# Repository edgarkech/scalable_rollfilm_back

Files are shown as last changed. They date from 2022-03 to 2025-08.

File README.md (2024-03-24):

# Scalable rollfilm back - 6x9...6x17...maybe even 6x24? 

_This is my attempt to re-engineer my old 6x12 rollfilm back into a scalable and adaptable design for large format cameras (4x5", 5x7", maybe 8x10")._
_

As a starting point - here's my old 6x12 TinkerCAD-design: https://www.thingiverse.com/thing:2894651 

## Project goals:
- of course a 3d printable and usable rollfilm back.
- different formats possible with type 120 rollfilm - from 6x6 up to 6x24 (depending on the targeted camera format) 
- The design should be scalable for being used with 4x5", 5x7" or even 8x10" large format cameras by just changing a handful of variables. I am not targeting medium format cameras/platforms like Mamiya RB/RZ, Bronica EC/GS/SQ/ETR, Hasselblad, Kiev88, Horseman 6x9, Graflex 2x3, Fuji GX or any other format smaller than 4x5". It _may_ be possible to scale down and fit the design to some 6x9/2x3" platforms, but I won't make any changes just for scaling down.  
- Improving my OpenSCAD skills. Learning to use it efficiently. Learning to do good parametric development/design.
- Learning git/github and sharing my code with other people
- Checking out the limits of home 3D printing with a very limited set of available tools

## Some technical goals:
- modular+parametric design
- all parts must be either 3D-printable or easily available via Amazon, eBay, Aliexpress or Temu.
- no special tools required besides a decent 3D printer and some common tools like little files, screwdrivers, sanding paper, cutter, scissors, ...
- no exotic third party parts/components
- form follows function
- KISS

## Early design decisions:
- keeping the basic concepts of my old 6x12 back
  - no explicit pressure plate
  - film "rollers" are fixed because it's easier to keep the measures/tolerances
- parts for the base plate won't be glued (except dark slide light seal) ==> dovetails
- film "roller"/re-director will be integrated and printed
- less "cubical" design than first version; maybe even flat enough to slide the back under the ground glass
- using the excellent BOSL2 library https://github.com/revarbat/BOSL2/wiki 
- no "extension" over the targeted platform and thus avoiding to move the film plane back (and using spacers or dedicated ground glassses): max format for 4x5" will be 6x12, max format for 5x7" will be 6x17

## update 2024-03-01
- looks like it will be a bit more re-engineering than just "porting" my old design to OpenSCAD. After having a look at some other (commercial) roll film backs like the Super Rollex or the Toyo family, I will also use some inspirations from there.

## update 2024-03-17 
- I always wanted to ge rid of the screws for locking cover and baseplate together, so I am now locking cover, baseplate_top and baseplate_bottom via dovetails.
- currently missing / not yet (re-) designed:
  - advancing lever ==> I am currently evaluating different ratchet mechanisms/designs
  - spool holders ==> will be quite simple parts
  - film counter ==> for the first version I will stick to the "spy window"
  - light seal for the baseplate bottom, but this is just a simple cubical to be glued into the base plate
  - STLs. I didn't print any parts yet and it will probably take one or two itereations for all the tolerances to match.

## update 2024-03-19
- printable parts are almost complete
  - avancing lever is derived from a little ratchet tool
  - film insert and cover got a counter window
  - film insert is prepared for a unrolling preventer (to be made of spring steel wire)
  - I am progressing with winders and spool holders
- now it's time for lots of test printing.
  - first test prints of the back plate revealed some small glitches (already fixed).
  - first complete prototype will hopefully available by the upcoming weekend...

 ## update 2024-03-24
 - meanwhile I printed all major parts.
 - the parts are fitting together, but showed the need for minor fixes/improvements (mostly printing related)
 - next iteration is leaving "mockup" stage and should be able to perform the basic mechanical functions (film loading, film advancing, disassembling without tools) 
   - clearance for the film spool inside the film insert was too tight (already fixed)
   - replaced some cube() objects with cuboid() from the BOSL2 library to round some edges (already done)
   - test with printed dark slide instead of sheet metal (cutting a raft from one of the prints), added file for printed dark slide
   - printing related optimizations
   - some minor parts are still missing: back plate light seal, winder blade, knob for film spool missing, lid for film counter window   

**Some very kind people asked me about the possibility to show their appreciation by donating to me.**

If you really felt somehow obliged to do so, then you should use https://paypal.me/EdgarKech :-) .
But I am also happy if you post pictures of your build to https://www.facebook.com/groups/3dprinting.and.analog.photography/

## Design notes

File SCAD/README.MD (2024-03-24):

CAUTION: 
The current version is not tested!!!

Preparation:

1.) Please make sure to install a fairly new version of OpenSCAD - versions 2021.01 or above are recommended and should be available for all common OS platforms.

2.) Please make sure to pull and install the following modules/libraries:

https://github.com/revarbat/BOSL2
==> we are using some modules/functions from this quite comprehensive library, e.g. dovetails, rectangular tubes, cuboids, trapezoids, ...

3.) Review and modify the configuration in config.scad to your needs. For the most common target "platforms" and formats you will just have to choose and uncomment some variables. Just read&follow the comments in the config.scad file. 

Modification beneath simple configuration:

Naming and scripting conventions (tbd)

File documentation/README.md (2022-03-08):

# Documentation

Here's an attempt at guiding the assembly and build process of the Scalable Rollfilm Back.

For now, it only contains NOTHING but we aim to create a step-by-step guide soon :)

**The assembly images are based on the 4x5" camera files**

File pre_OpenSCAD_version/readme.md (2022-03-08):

Here you can find the "old" files from my initial TinkerCAD-version.
You will find a set of STL files as well as f3d files.
For hints about the old version, have a look at https://www.thingiverse.com/thing:2894651

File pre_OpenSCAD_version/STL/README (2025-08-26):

### Summary
Roll film back for shooting 6x12cm format with 4x5 cameras.
The basic idea is borrowed from the chinese DaYi / ShenHao roll film backs.
Main design principle is to keep it as simple as possible and avoiding special or exotic third party parts or tools.

# Third party parts:
2x rods or tubes with a diameter of 6mm and a length of 72mm
2x countersunk screws M6x30mm
2x butterfly or knurled nuts M6
1x dark red gel with about 14mm for the frame counter window (optional)
1x sheet metal 170x70x0.5mm for dark slide (170mm is about the minimum length)
2x sheet metal from a tin can, about 20x60mm
a little bit of plastic glue
1x velvet ribbon, about 10x90mm as light seal for the dark slide

Pictures shot with my design can be found here:
https://www.flickr.com/search/?text=6x12%20istillshootfilm%20buyfilmnotmegapixels%20back&sort=date-posted-desc

### Changes
- 2020-01-25 updated the base plate top (slightly higher light seal, corrected flange measurements)
- 2020-01-26 updated the cover because it was a little bit to tight on the film insert. New version has about 0.2mm more space on each side. This helps also, if you are using some colored filament and thus have to paint the inside of the cover in black. 
- 2020-02-02 updated base plate bottom and base plate top to new version 2.4.
I added a wall at one side and on the other side an indent for a light seal (glue velvet ribbon into the indent.
Also updated the pictures to ones from the latest build and removed the ones from the old version.
- 2020-02-07 tried to get the previews of all STL-files back. No changes, just renaming the files to reflect the overall version
- 2020-02-08 added link to my flickr page
- 2020-03-06 updated base plate top to v2.5 because of a little error.
- 2020-03-19 updated text and instructions regarding dark slide (now minimum length of about 170mm)
- 2021-08-11 I finally managed to export my design files from TinkerCAD to Fusion360 and then download/upload as .f3d files , so interested/gifted designers may now be able to modify my design in a more convenient way than using .stl files...

### Print Settings
Printer brand:
- any brand will do, as long as you have a basic understanding of printing and especially bed leveling

Printer:
- any model will do, as long as you have a basic understanding of printing and especially bed leveling

Rafts:
- if you have problems with printing bed adhesion, rafts could be an option, but I'd rather recommend doing proper bed leveling

Resolution:
- 0.1-0.15

Infill:
- depending on part, see below

Filament brand:
- choose your favorite

Filament color:
- preferably black

Filament material:
- PLA, ABS, PETG

### Notes:
We have to get the roll film back really light tight, so make sure to use some kind of really opaque filament.
Make sure to print at least 4 walls and 8 bottom/top layers - we have to get some parts really light tight (base plate, film insert, cover, counter window blade)!

- base plate bottom: 0.1mm layer, 100% infill, no support, 3mm brim
- base plate top: 01.mm layer, 100% infill, no support, 3mm brim
- film insert: 0.1mm layer, 66%infill, support, 3mm brim
- cover: 0.1mm layer, 66% infill, support, 3mm brim
- all smaller parts: 0.1mm layer, 100% infill, no support, 3mm brim

### Post-Printing
# base plate
After removing the brim and cleaning up the edges of the base plate parts, glue the velvet ribbon into the indent.
Then glue the "base plate top" to the "base plate bottom". Make sure that no glue gets into the dark slide slot, otherwise it'll get very difficult to pull in/out the dark slide.
Glue the bottom wall into the slot at the bottom side 

# film insert
Remove brim and support structures, then clean up the edges with sandpaper or a little file.
Press the two 6mm rods into their places at the bottom. They should be even with the bottom.
Clean up the edges of your tin can stripes with a little file. Put the stripes into the slots in the inner walls. Bend the stripes down so they will put a little bit tension onto the film roll and prevent the film of unrolling.
Counter window blade and film holder brackets:
You may use a file to trim those parts a little bit so they slide into their respective guides. Be careful not to trim away too much - you should be able to move them in their guides with just a little force.

# cover
Remove brim and support structures from the cover.
Check with a small, but very bright flashlight, if your cover (upper side, end faces) is really light tight. If not, paint the inside of the cover with black paint.
If it is still not light tight, print the cover with black filament and 100% infill.

# winders / winder knobs
Once again, remove brim and sharp edges. On the smaller side of the winder plate use a file or sandpaper to make it a bit "wedgy". Then press it into the slot of the winder (the part with the cube on top of the cylinder. Put the winders into the film insert and press the winder knob onto it -  the bigger one on the right hand side, the smaller on the left (maybe you have to add a drop of glue).  

# dark slide
Make sure you have a perfectly flat sheet metal 170x70x0.5mm. Bend the last few millimeters to a grip (fold 5mm then bend the 5mm double to a right angle).
Now the most important thing:
As we don't have a light seal, we simply just don't pull out the dark slide completely. Instead we make marks onto the slide which show us, how far we can pull it out.
Just put the dark slide into the dark slide slot of the back and pull it out until the window frame is completely open. Now mark the position on the darkslide (for example with small notches on the sides of the dark slide).

### Testing & correcting film guidance
You will have to sacrifice one or two rolls of film to get everything working.
You may notice that the slot where the film is pulled through, is very tight.
If it is too tight, then just apply strips of tape onto the base plate's guides.

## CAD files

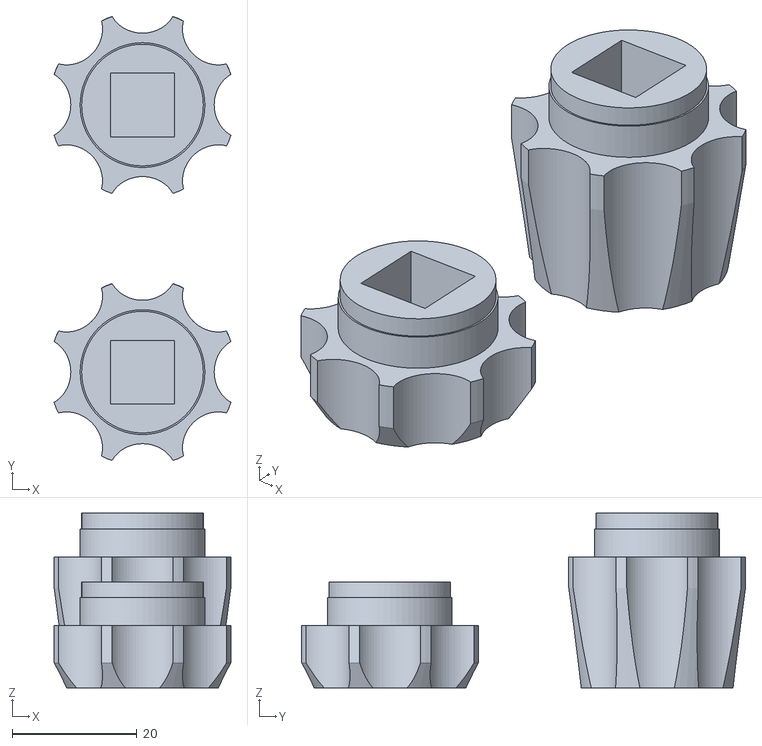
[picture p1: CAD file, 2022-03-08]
pre_OpenSCAD_version/STL/winder_knobs_v2.4.stl
28.4 x 71.2 x 28.0

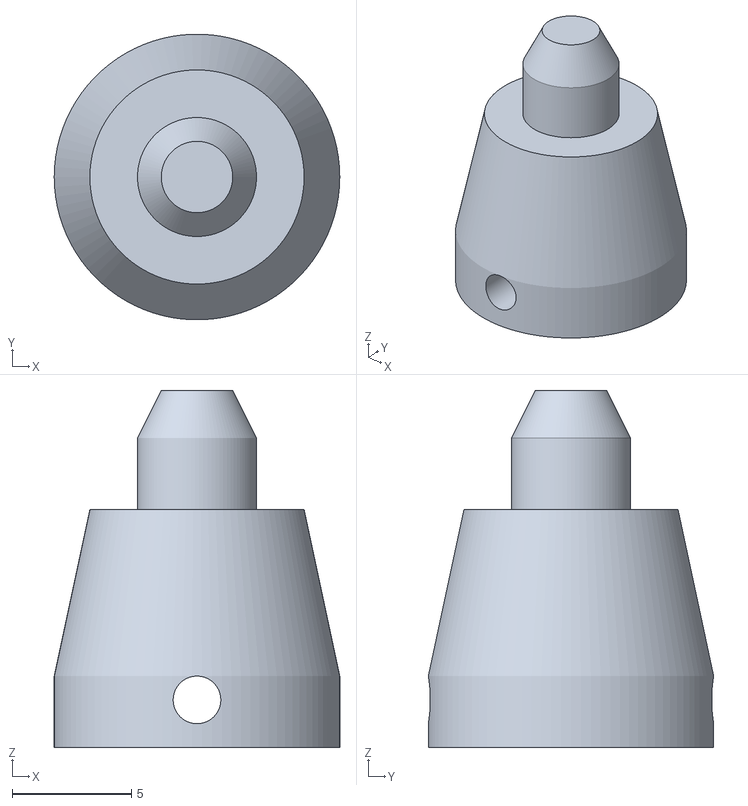
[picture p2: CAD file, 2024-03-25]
STL/spoolholder.stl
12.0 x 12.0 x 15.0

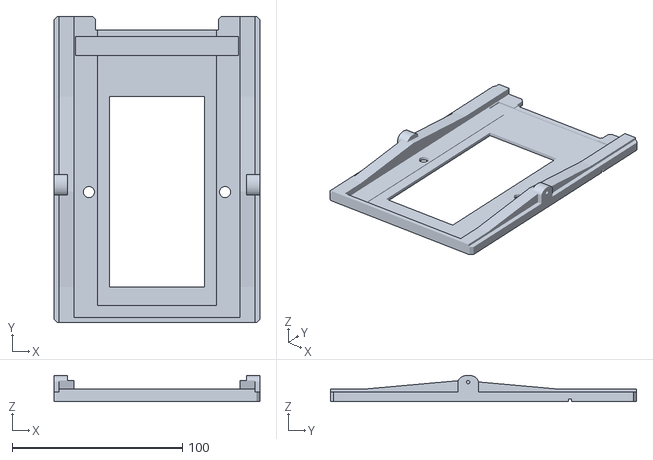
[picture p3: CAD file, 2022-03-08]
pre_OpenSCAD_version/STL/base_plate_bottom_v2.4.stl
121.0 x 180.0 x 15.5

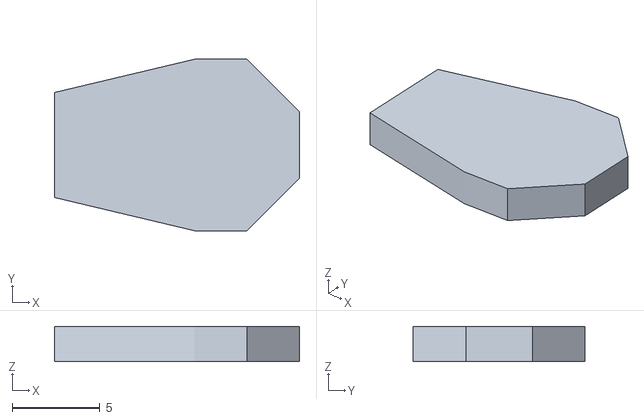
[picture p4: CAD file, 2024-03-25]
STL/winderblade.stl
14.0 x 9.80 x 2.00

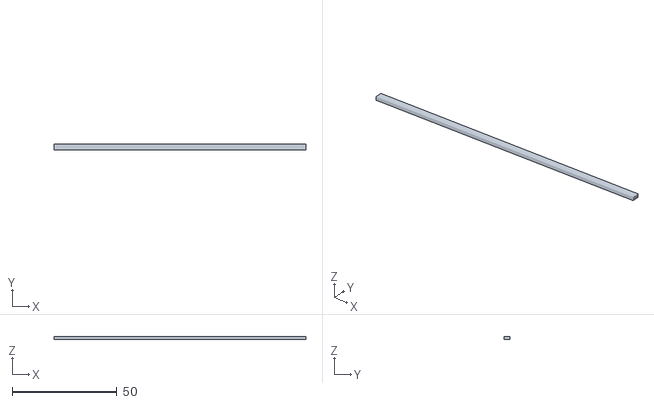
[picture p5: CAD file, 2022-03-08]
pre_OpenSCAD_version/STL/bottom_wall_v2.4.stl
120.0 x 3.00 x 1.50

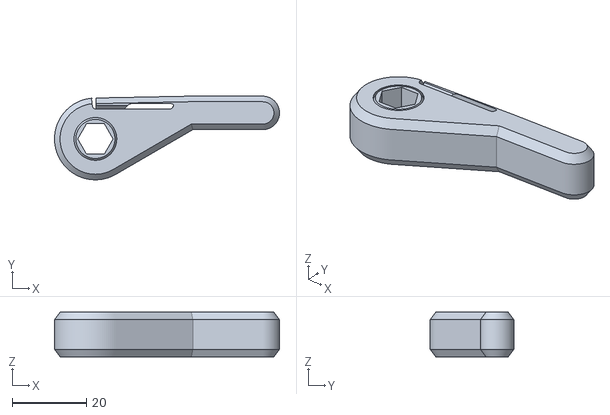
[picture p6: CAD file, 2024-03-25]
STL/advancing_lever_6stops.stl
60.5 x 22.5 x 12.0

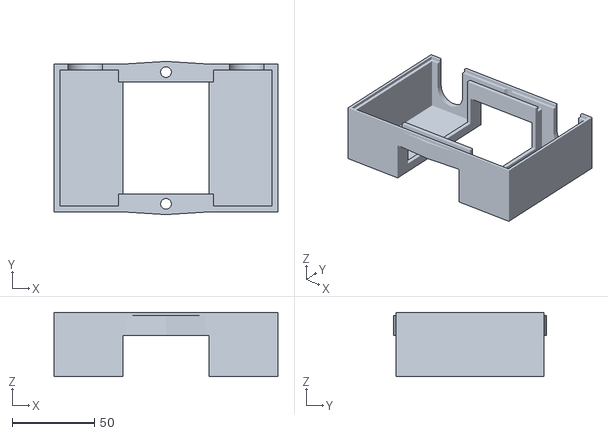
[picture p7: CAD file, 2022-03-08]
pre_OpenSCAD_version/STL/cover_v2.4.stl
136.0 x 93.0 x 39.0

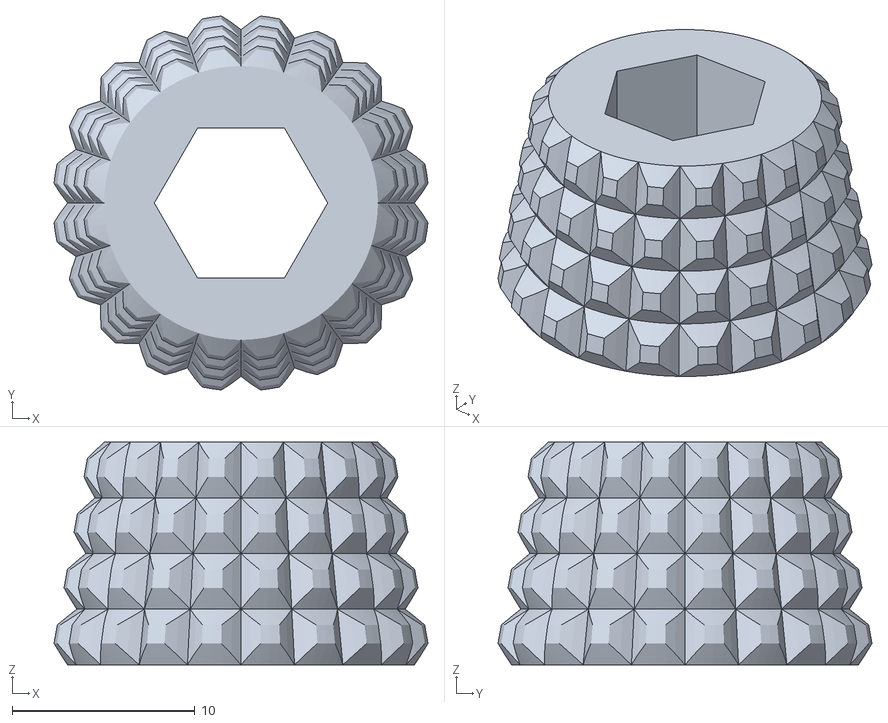
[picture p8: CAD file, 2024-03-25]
STL/winderknob.stl
20.5 x 20.5 x 12.2

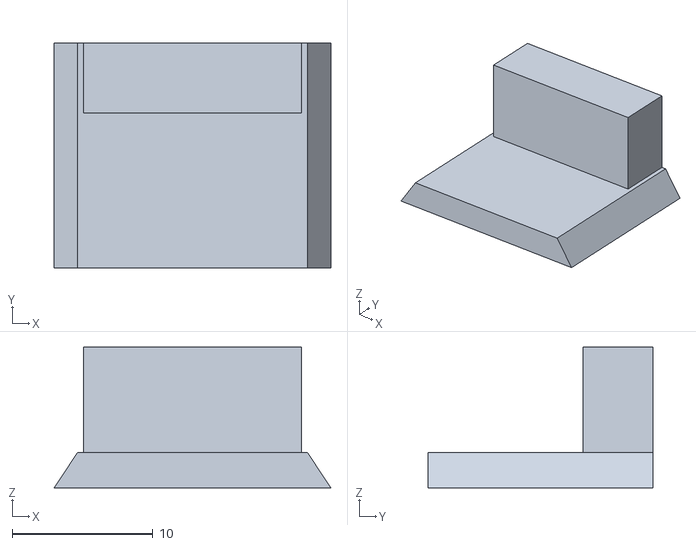
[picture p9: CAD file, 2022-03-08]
pre_OpenSCAD_version/STL/counter_window_blade_v2.4.stl
19.7 x 16.0 x 10.0

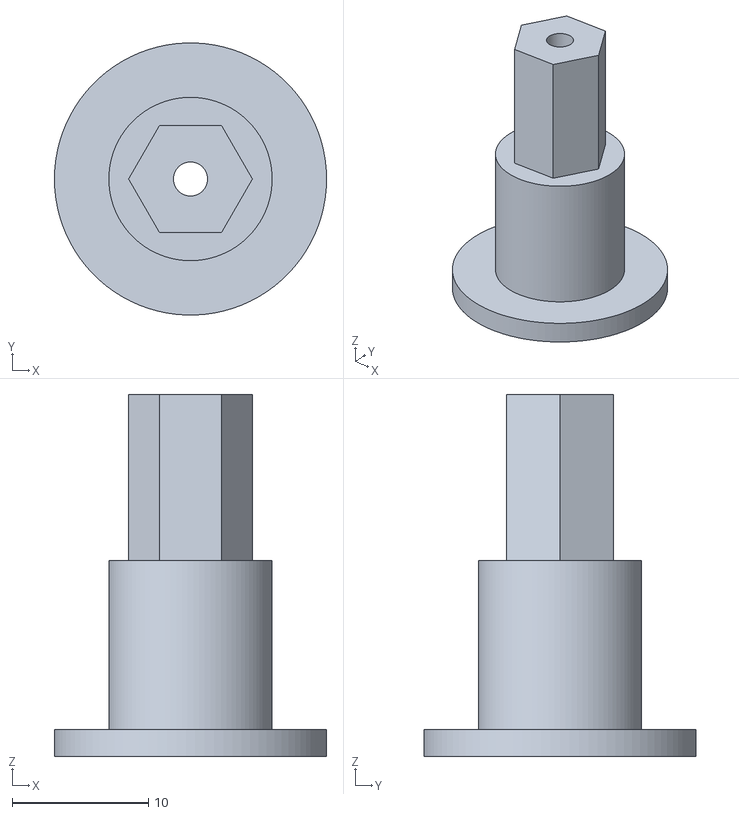
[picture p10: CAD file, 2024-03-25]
STL/winder.stl
20.0 x 20.0 x 26.6

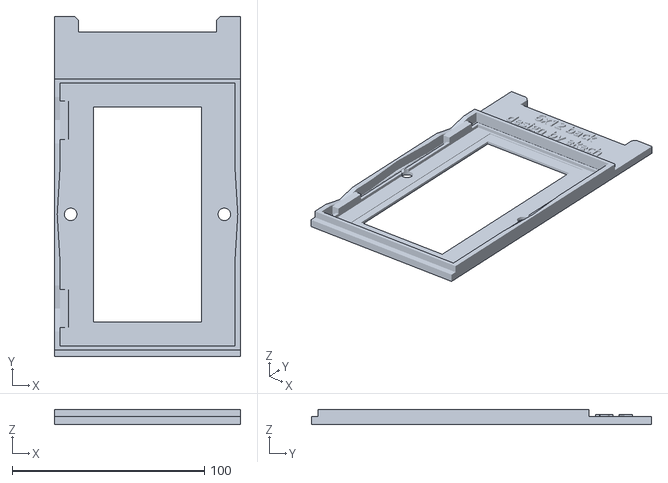
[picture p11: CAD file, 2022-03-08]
pre_OpenSCAD_version/STL/base_plate_top_v2.5.stl
97.0 x 177.0 x 8.00

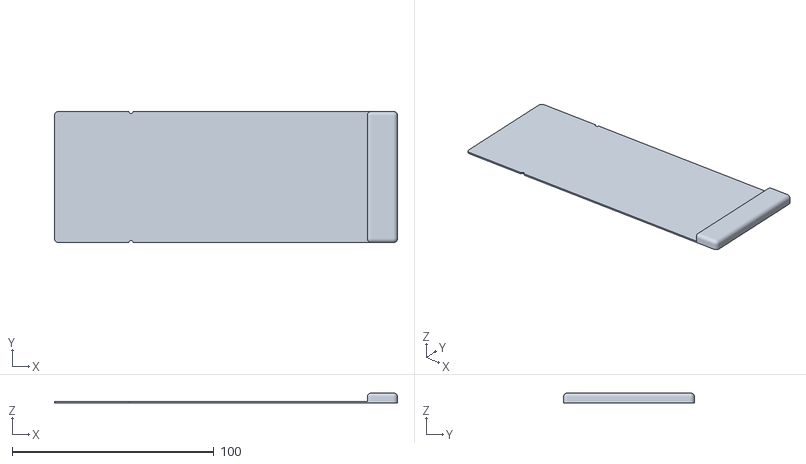
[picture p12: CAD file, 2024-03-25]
STL/dark_slide.stl
170.2 x 65.0 x 5.00

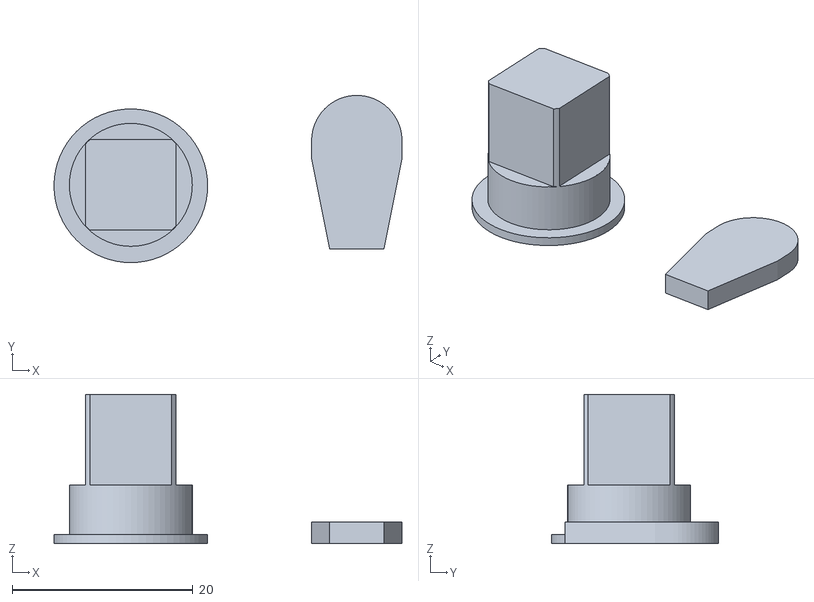
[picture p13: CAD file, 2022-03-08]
pre_OpenSCAD_version/STL/winders_v2.4.stl
38.5 x 18.5 x 16.5

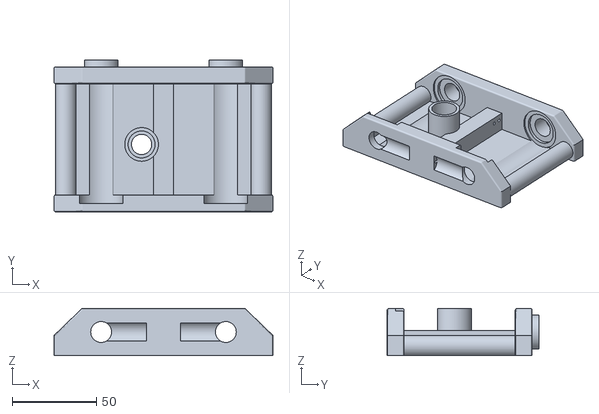
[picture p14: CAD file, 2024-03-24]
STL/film_insert.stl
130.0 x 90.0 x 28.0

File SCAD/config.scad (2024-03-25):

/*
This is the base configuration file for the scalable rollfilm back
# we are not using the exact ANSI measures, but slightly rounded measures
*/

/*
// target platforms
// (currently only a reminder to put target platform specific variables into separate include files)
// # 4x5 with a "native" format of 6x12 (smaller formats via different backplates/masks)
// # 5x7 with a "native" format of 6x17 or 6x12
// # 8x10 with a "native" format of 6x24 or 6x17
// # custom (e.g. for dedicated 6x17 or 6x24 cameras)

// target formats / aspect ratios / framesizes
// # 6x6 / 1:1 / 56x56 / 12 frames
// # 6x7 / 6x7 / 56x65 / 10 frames 
// # 6x8 / 3x4 / 56x75 / 9 frames
// # 6x9 / 2:3 / 56x84 / 8 frames
// # 6x10 / 9:16 / 56x100 / 7 frames
// # 6x12 / 1:2 / 56x112 / 6 frames
// # 6x13 / 9:21 / 56x131
// # 6x14 / 2:5 / 56x136 / 5 frames
// # 6x17 / 1:3 / 56x168 / 4 frames
// # 6x24 / 1:4 / 56x224 / 3 frames
*/

/*
#############################################################################################
# with the following variables we control the frame format and the targeted "platform"      #
# (currently setup for a 6x12 back for 4x5" cameras)                                        #
#############################################################################################
*/

vCassetteLength = 170; // ANSI: 159.92 ... ?
vCassetteWidth = 120.5; // ANSI: 120.24 ... 121.03
vCassetteHeight = 8; // this is not ANSI, but just an assumption for the thickness of our backplate
vCassetteBorderOffset = 76; // we will take the mid of the film frame as 0 for the x axis
vLightTrapSlotOffset = 139; // CAUTION: this offset is measured from the back, not from the center of the frame
vLightTrapSlotWidth = 2.2; // ANSI uses a trapezoid for the light seal. we are just using a cube with about 2mm width
vGraflokWidth = 5; // measurement from a Horseman 6x9 roll film back for 4x5"
vGraflokHeight = 6; // measurement from a Horseman 6x9 roll film back for 4x5"

/*
############################################################################################ 
## adjust the format here according to the mentioned sizes above! 
*/
vFrameLength = 112;
vFrameWidth = 56;
/*
############################################################################################
*/

vFilmPlaneDistance = 5; // ANSI: 5
vFilmThickness = 0.4; // we are calculating 0.12...0.18 for the film + about the same amount for the back paper + a little bit tolerance

vFilmrollDiameter = 26; // max film roll diameter (empirical)
vFilmrollLength = 66; // max film roll length (empirical)
vFilmSpoolClearance = 5; // the space we need for inserting the film spool (empirical)
vFilmSpoolAxisDiameter = 12;
vFilmSpoolAxisLightSealDiameter = 20;
vFilmSpoolAxisLightSealDepth = 2;
vFilmSpoolAxisExtension = 4; // should be at least equal to the lower walls of the cover 

vFilmRoller_d = 12; // while 16 or even more would require less film "bending", it would also require more precious space 

vCoverWallThickness = 2; // 2 should be sufficient for opacity and rigidity
vCoverCutoutTolerance = 0.2;

/*
#############################################################################################
# PLEASE DO NOT CHANGE ANYTHING BELOW THIS POINT UNLESS YOU REALLY KNOW WHAT YOU ARE DOING! #
#############################################################################################
*/

// general tolerance
vTolerance = 0.2;

// some generic variables
$fn = 90; // we are using 90 fragments for cylinders and similar objects

vFilmInsert_w = 86; // we have to add at least 7mm to each side of the film roll, initially we used a total of 80

vDarkSlideLength = vCassetteLength - 10;
vDarkSlideWidth = 65; // the dark slide will be 64...65mm wide, but we need a enough room on the sides
vDarkSlideHeight = 0.8; // we calculate with 0.8 - the slot for the dark slide will be 1.0 
vDarkSlideSealLength = 10;
vDarkSlideSealWidth = vDarkSlideWidth;
vDarkSlideSealHeight = 1;
vDarkSlideGripCutout = 5;


vBackplateTopLength = vCassetteLength - 3; // we need a stop at the back end of the backplate 
vBackplateTopWidth = 102; // we are starting with the measurement from the original version (98)

vBackplateEdgeRadius = 1;


// we derive most measures and variables from the above variables

// base plate bottom outer
vBaseplate_l = vCassetteLength;
vBaseplate_w = vCassetteWidth;
vBaseplate_h = vCassetteHeight;
vBaseplate_offsetX = -vCassetteBorderOffset;
vBaseplate_offsetY = -vCassetteWidth/2;
vBaseplate_offsetZ = 0;

vFilmframe_l = vFrameLength;
vFilmframe_w = vFrameWidth;
vFilmframe_h = vCassetteHeight;
vFilmframe_offsetX = -vFilmframe_l/2;
vFilmframe_offsetY = -vFilmframe_w/2;
vFilmframe_offsetZ = 0;

vTopplateCutout_l = vBackplateTopLength + vTolerance;
vTopplateCutout_w = vBackplateTopWidth + vTolerance;
vTopplateCutout_h = vCassetteHeight-3;
vTopplateCutout_offsetX = vCassetteLength - vCassetteBorderOffset - (vTopplateCutout_l/2);
vTopplateCutout_offsetY = 0;
vTopplateCutout_offsetZ = vCassetteHeight;

vDarkSlideCutout_l = vDarkSlideLength;
vDarkSlideCutout_w = vDarkSlideWidth + 1;
vDarkSlideCutout_h = vCassetteHeight;
vDarkSlideCutout_offsetX = -vCassetteBorderOffset+10;
vDarkSlideCutout_offsetY = -vDarkSlideCutout_w/2;
vDarkSlideCutout_offsetZ = 2; // maybe reduce to 1.8

vDarkSlideGripCutout_l = vDarkSlideGripCutout;
vDarkSlideGripCutout_w = vDarkSlideWidth + 1;
vDarkSlideGripCutout_h = vCassetteHeight;
vDarkSlideGripCutout_offsetX = vCassetteLength - vCassetteBorderOffset - vDarkSlideGripCutout;
vDarkSlideGripCutout_offsetY = -vDarkSlideGripCutout_w/2;
vDarkSlideGripCutout_offsetZ = 0;


// remove?
vDarkSlideSealCutout_l = vDarkSlideSealLength;
vDarkSlideSealCutout_w = vDarkSlideWidth;
vDarkSlideSealCutout_h = vCassetteHeight;
vDarkSlideSealCutout_offsetX = vCassetteLength - vCassetteBorderOffset - vDarkSlideGripCutout - vDarkSlideSealCutout_l - 5;
vDarkSlideSealCutout_offsetY = -vDarkSlideWidth/2;
vDarkSlideSealCutout_offsetZ = 1.2;

vBottomLightTrapSlot_l = vLightTrapSlotWidth;
vBottomLightTrapSlot_w = vBaseplate_w;
vBottomLightTrapSlot_h = 1;
vBottomLightTrapSlot_offsetX = vLightTrapSlotOffset - vCassetteBorderOffset;
vBottomLightTrapSlot_offsetY = -vBottomLightTrapSlot_w/2;
vBottomLightTrapSlot_offsetZ = 0;

vGraflokCutout_l = vBaseplate_l;
vGraflokCutout_w = vGraflokWidth;
vGraflokCutout_h = vCassetteHeight;
vGraflokCutout_offsetX = vBaseplate_offsetX;
vGraflokCutout_offsetY1 = -vCassetteWidth/2;
vGraflokCutout_offsetY2 = vCassetteWidth/2 - vGraflokCutout_w;
vGraflokCutout_offsetZ = vGraflokHeight;



vTopplate_l = vBackplateTopLength;
vTopplate_w = vBackplateTopWidth - vTolerance;
vTopplate_h = vCassetteHeight-3;
vTopplate_offsetX = vCassetteLength - vCassetteBorderOffset - (vTopplate_l/2);
vTopplate_offsetY = 0;
vTopplate_offsetZ = vCassetteHeight;

vFilmbedCutout_l = vFrameLength + 4 + vFilmRoller_d + 2 ; // we add 8mm on each side to keep the film flat
vFilmbedCutout_w = vFrameWidth + 8; // backpaper is normally about 63mm, so we add 4mm on each side to our 56mm film frame
vFilmbedCutout_h = vTopplate_h; // we just take the full height
vFilmbedCutout_offsetX = -vFilmbedCutout_l/2;
vFilmbedCutout_offsetY = -vFilmbedCutout_w/2;
vFilmbedCutout_offsetZ = vFilmPlaneDistance - vFilmThickness;

vFilmInsertCutout_l = vFilmbedCutout_l + (2*vTolerance);
vFilmInsertCutout_w = vFilmInsert_w + 2*vTolerance;
vFilmInsertCutout_h = vTopplate_h;
vFilmInsertCutout_offsetX = -vFilmInsertCutout_l/2;
vFilmInsertCutout_offsetY = -vFilmInsertCutout_w/2;
vFilmInsertCutout_offsetZ = vFilmPlaneDistance;

vCoverCutout_l = vFilmbedCutout_l + 8 + (2*vTolerance);
vCoverCutout_w = vFilmInsert_w + 8 + (2*vTolerance);
vCoverCutout_h = vTopplate_h;
vCoverCutout_offsetX = -vCoverCutout_l/2;
vCoverCutout_offsetY = -vCoverCutout_w/2;
vCoverCutout_offsetZ = vFilmPlaneDistance;

vCoverLightSeal_l = vFilmbedCutout_l + 4 - (2*vTolerance);
vCoverLightSeal_w = vFilmInsert_w + 4 - (2*vTolerance);
vCoverLightSeal_h = 2 - vTolerance;
vCoverLightSeal_wall = 2 - (2*vTolerance);
vCoverLightSeal_offsetX = 0; // rect_tube centers by default, so we can leave the offset at 0
vCoverLightSeal_offsetY = 0; // rect_tube centers by default, so we can leave the offset at 0
vCoverLightSeal_offsetZ = vFilmPlaneDistance;


// film insert

vFilmInsertBaseplate_l = vFrameLength + 4;
vFilmInsertBaseplate_w = vFilmInsert_w;
vFilmInsertBaseplate_h = 3;
vFilmInsertBaseplate_offsetX = -vFilmInsertBaseplate_l/2;
vFilmInsertBaseplate_offsetY = -vFilmInsertBaseplate_w/2;
vFilmInsertBaseplate_offsetZ = vFilmPlaneDistance;

vFilmRoller_w = vFilmInsertBaseplate_w;
vFilmRoller_offsetX = vFilmInsertBaseplate_offsetX;
vFilmRoller_offsetY = vFilmInsertBaseplate_offsetY;
vFilmRoller_offsetZ = vFilmPlaneDistance + vFilmRoller_d/2;
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

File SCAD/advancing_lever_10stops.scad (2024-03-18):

$fn = 120;

// "old" variables

rotate_y = 180;
//rotate_z = -30;
rotate_z = 0;
//pos_hex = -2;
pos_hex = 0; // EK 20240317 

vTolerance = 0.2;

vBodyOuter_d = 22;
vBodyLever_l = 25;
vBodyLeverEnd_d = 9;
vBodyEdgeCut = 2;
vLeverExtension_d = vBodyLeverEnd_d;
vLeverExtension_l = 20;


// calling/executing all modules		
union() rotate([0,rotate_y,rotate_z])
{
	translate([0,0,0]) eye();
  translate([0,0,0]) body();
    translate([0,0,0]) lever_extension();
}

 
module body()
{
  difference()
  {
    union()
    {
      // outer hull
        hull()
      {
        translate([0,0,0]) cylinder(d=19,h=12,center=true);
        translate([0,0,0]) cylinder(d=22,h=8,center=true);
        translate([-25,7,0]) cylinder(d=6,h=12,center=true);
        translate([-25,7,0]) cylinder(d=9,h=8,center=true);
      }
    }
    union()
    {
      // cage cutout
      translate([0,0,0]) cylinder(d=11.5,h=12.2,center=true);
      hull()
      {
        //translate([0,0,0]) cylinder(d=10.8,h=12.2,center=true);
        translate([0,0,0]) cylinder(d=11.2,h=12.2,center=true);
        translate([0,0,0]) cylinder(d=16.8,h=2.8,center=true);
      }
      
      // ratchet cutout
      hull()
      {
        translate([-0.0,6.0,0]) cylinder(d=1,h=4,center=true);
        translate([-20,6.0,0]) cylinder(d=1,h=4,center=true);
        //translate([-0.2,10.6,0]) cylinder(d=1.6,h=16,center=true);
        //translate([-20,10.6,0]) cylinder(d=1.6,h=16,center=true);
        translate([-0.2,10.5,0]) cylinder(d=2,h=16,center=true);
        translate([-20,10.5,0]) cylinder(d=2,h=16,center=true); 
      }
    }
  }
  
  // ratchet
  intersection()
  {
    union()
    {
      difference()
      {
        hull()
        {
          translate([0,0,0]) cylinder(d=19,h=12,center=true);
          translate([0,0,0]) cylinder(d=22,h=8,center=true);
          translate([-25,7,0]) cylinder(d=6,h=12,center=true);
          translate([-25,7,0]) cylinder(d=9,h=8,center=true);
        }
        hull()
        {
          //translate([-20,7,0]) cylinder(d=4,h=12,center=true);
          //translate([-10,7,0]) cylinder(d=4,h=12,center=true);
          translate([-20,7.5,0]) cylinder(d=4,h=12,center=true);
          translate([-10,7.5,0]) cylinder(d=4,h=12,center=true);
          translate([-7,4,0]) cylinder(d=4,h=12,center=true);
        }
      }
    }
    union()
    {
      hull()
      {
        translate([-0.6,6.6,0]) cylinder(d=1,h=4,center=true);
        translate([-21,6.6,0]) cylinder(d=1,h=4,center=true);
        translate([-0.6,11.0,0]) cylinder(d=1,h=16,center=true);
        translate([-21,11.0,0]) cylinder(d=1,h=16,center=true);
      }
    }
  }
}

module lever_extension()
{
    hull()
      {
        translate([-25,7,0]) cylinder(d=6,h=12,center=true);
        translate([-25,7,0]) cylinder(d=9,h=8,center=true);
        translate([-45,7,0]) cylinder(d=6,h=12,center=true);
        translate([-45,7,0]) cylinder(d=9,h=8,center=true);
      }
    }



module eye() 
{
  difference()
  {
    union()
    {
      hull()
      {
        translate([0,0,0]) cylinder(d=10,h=12,center=true);
        translate([0,0,0]) cylinder(d=16,h=3,center=true);
      }
    }
    union()
    {
      translate([0,0,pos_hex]) cylinder(d=6.65,h=12,center=true); // HEX Zylinder
      difference()
      {
        translate([0,0,pos_hex]) cylinder(d=7.7,h=12,center=true,$fn=6); // HEX Sechseck
      }
      // for(i=[30:60:360]) // 6 stops
      for(i=[30:36:360]) // 10 stops    
      {
        rotate([0,0,i])
        {
          hull()
          {  // Ratsche
            translate([-6.0,-0.3,0]) cylinder(d=1,h=4,center=true);
            translate([-6.0,-21,0]) cylinder(d=1,h=4,center=true);
            translate([-10,-0.3,0]) cylinder(d=1,h=16,center=true);
						translate([-10,-21,0]) cylinder(d=1,h=16,center=true);
          }
        }
      }  
    }
  }
}

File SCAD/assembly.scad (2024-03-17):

// BOSL2 includes (https://github.com/revarbat/BOSL2/wiki)  
include <BOSL2/std.scad>
include <BOSL2/joiners.scad>

// including our configuration file
include <config.scad>;

// include all single parts from the other SCAD files

// baseplate bottom
// color([20,0,170, 0.75]){
include <baseplate_bottom.scad>;
//}

// baseplate top
//color([0,20,230, 0.75]){
include <baseplate_top.scad>;
//}

// film insert
//color([0,230,0, 0.85]){
include <film_insert.scad>;
//}

// cover
//color([0,230,0, 0.85]){
//include <cover.scad>;
//}

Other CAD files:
pre_OpenSCAD_version/STL/film_insert_v2.4.stl
STL/cover.stl
pre_OpenSCAD_version/STL/film_holder_bracket_v2.4.stl
STL/baseplate_bottom.stl
SCAD/advancing_lever_6stops.scad
SCAD/baseplate_bottom.scad
SCAD/baseplate_top.scad
SCAD/cover.scad
SCAD/dark_slide.scad
SCAD/film_insert.scad
SCAD/spoolholder.scad
SCAD/winder.scad
SCAD/winderblade.scad
SCAD/winderknob.scad
STL/baseplate_top.stl
pre_OpenSCAD_version/F3D/base_plate_bottom.f3d
pre_OpenSCAD_version/F3D/base_plate_top.f3d
pre_OpenSCAD_version/F3D/bottom_light_seal.f3d
pre_OpenSCAD_version/F3D/counter_window_shutter_blade.f3d
pre_OpenSCAD_version/F3D/cover.f3d
pre_OpenSCAD_version/F3D/film_holder_bracket.f3d
pre_OpenSCAD_version/F3D/film_insert.f3d
pre_OpenSCAD_version/F3D/winder_knobs.f3d
pre_OpenSCAD_version/F3D/winders.f3d

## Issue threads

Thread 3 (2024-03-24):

Missing winder blades

edgarkech, 2024-03-24:
as of 2024-03-24 the blades for the winders are missing

edgarkech, 2024-03-24:
this should be a small rectangular piece with 2x10x15mm which has to be pressed into the slot at the bottom of the winders.

edgarkech, 2024-03-25:
SCAD and STL files added to pre-production-testing branch

Closed 2024-03-25.

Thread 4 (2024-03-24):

missing back plate lightseal

edgarkech, 2024-03-24:
as of 2024-03-24 the lightseal for the backplate missing

edgarkech, 2024-03-24:
this is just a cubical of 2x2x120.5 which has to be glued into the slot on the backside of the base plate bottom

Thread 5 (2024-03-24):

missing knob for winder

edgarkech, 2024-03-24:
as of 2024-03-24 the knob for holding the winder axis is missing

edgarkech, 2024-03-24:
this is just a knob with a diameter of 20mm and a hex-hole to be put/screwed onto the hex axis of the winder.

edgarkech, 2024-03-25:
SCAD and STL files added to pre-production-testing branch #

Closed 2024-03-25.

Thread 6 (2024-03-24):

film counter window needs a lid

edgarkech, 2024-03-24:
as of 2024-03-24 the film counter window is just an open tube. for real usage we need some kind of lid for the film counter window.

edgarkech, 2024-03-24:
idea:
- shortening the tube on the film insert and adding dovetails with a slider to the inside of the cover

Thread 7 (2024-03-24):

add complete bill of materials

edgarkech, 2024-03-24:
as of 2024-03-24 there is neither a full BOM nor hints/settings for printing

paulbeard, 2025-08-25:
Sounds like this is 100% ready for prime time. Is there somewhere to see a WIP version or vision of where it is right now? I can read the issues here but not sure what it all means. I'd be interested in building one.

paulbeard, 2025-09-17:
I have built two of these (broke some crucial parts on the first one) and
it seems to work pretty well. I was able to extend the 3D printing ethos to
the darkslide (printed it at .07mm with a final thickness of .7mm) and the
screws. I had to make the screws because the commercial ones didn't really
countersink, preventing the back from sliding into a graflock back. I also
had to edit some of the base plate…those rounded bits that might be for a
springlock back were too wide. I could use headless metal screws/threaded
rod but there's not a lot of material for it to bite into on the base
plate. some pictures of the contraption here…one test roll in the one I
wrecked and I'll develop the stuff I shot tonight and see where I am on
this one.

On Mon, Aug 25, 2025 at 10:28 PM Edgar Kech ***@***.***>
wrote:

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

--
Paul Beard / www.paulbeard.org/

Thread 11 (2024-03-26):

too much friction/resistance when advancing film

edgarkech, 2024-03-26:
with the fixed&printed film redirectors there is a lot of friction/resistance to overcome when advancing film. This will stress especially the winderblades and the winder axis. In my test I sheared off the hexagonal part of the winder axis.

idea:
replacing the fixed film redirectors with proper film rollers should reduce the friction significantly. I am thinking about using a 8mm steel axis with a bunch of 8x12x12mm PA bushings as rollers. Unfortunately this will require some major changes to the film insert to achieve the required tolerances for the axis position.

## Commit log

2022-03-08 added old f3d files as reference
    [base_plate_bottom.f3d, base_plate_top.f3d, bottom_light_seal.f3d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]
2024-03-01 restructered files
    restructured files, also added an assembly file which includes all relevant single files
    [assembly.scad, baseplate_bottom.scad, baseplate_top.scad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]
2024-03-17 too many changes to list
    # cover and baseplate_top are now locked together with the baseplate_bottom via dovetails;
    [assembly.scad, baseplate_top.scad, config.scad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]
2024-03-17 initial prototyping versions
    CAUTION: this STL files are currently untested
    [baseplate_bottom.stl, baseplate_top.stl, cover.stl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]
2024-03-17 cutout for dark slide grip corrected
    [baseplate_top.stl]
2024-03-18 small corrections after first test print
    [baseplate_bottom.stl, baseplate_top.stl, cover.stl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]
2024-03-18 small corrections after first test prints
    [config.scad]
2024-03-24 SCAD files for initial test prints
    SCAD files for initial test prints
    [advancing_lever_6stops.scad, baseplate_bottom.scad, cover.scad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]
2024-03-24 STL files for initial tests
    STL files for initial tests
    [advancing_lever_6stops.stl, cover.stl, dark_slide.stl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]
2024-03-24 fix for insert
    add more clearance for the film spools
    [config.scad, film_insert.scad]
2024-03-24 fix for insert
    STL with added clearance for film spool
    [film_insert.stl]
2024-03-25 added variables for small parts
    added variables for small parts
    [config.scad]
2024-03-25 fixes after first dry test with film
    - spoolholder: changed from cylindrical body to cone
    - winder hex axis was too weak
    - winderknob adapted to new winder hex axis diameter
    - lever adapted to new winder hex axis diameter
    - added indents to dark slide
    [advancing_lever_6stops.scad, config.scad, dark_slide.scad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]
